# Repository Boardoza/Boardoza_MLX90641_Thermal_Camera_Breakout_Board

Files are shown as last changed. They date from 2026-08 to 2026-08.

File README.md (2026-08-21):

# Boardoza MLX90641 Thermal Camera Breakout Board

The **Boardoza MLX90641 Breakout Board** is a compact and high-performance thermal imaging solution built around the **Melexis MLX90641** far-infrared thermal sensor array. Featuring a **16x12 pixel thermal resolution**, the sensor delivers **192 independent temperature measurement points** for accurate non-contact thermal analysis and object detection applications.

Designed for compatibility with both **3.3V and 5V systems**, the board communicates over a high-speed **I<sup>2</sup>C interface** and supports configurable refresh rates up to **64Hz**. With a wide measurement range from **-40°C to +300°C** and a **55° X axis and 35° Y axis Field of View**, this breakout board is ideal for industrial monitoring, predictive maintenance, thermal mapping, robotics, occupancy sensing, smart appliances, and advanced embedded thermal imaging projects.

## [Click here to purchase!](https://www.ozdisan.com/ureticiler/boardoza)

|Front Side|Back Side|
|:---:|:---:|
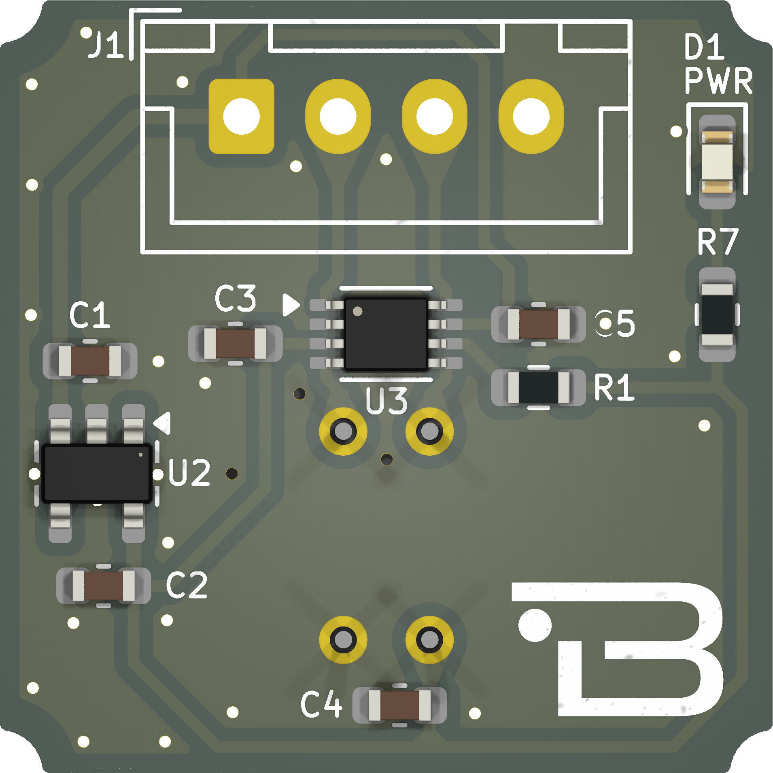
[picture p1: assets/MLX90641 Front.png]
MLX90641 Front
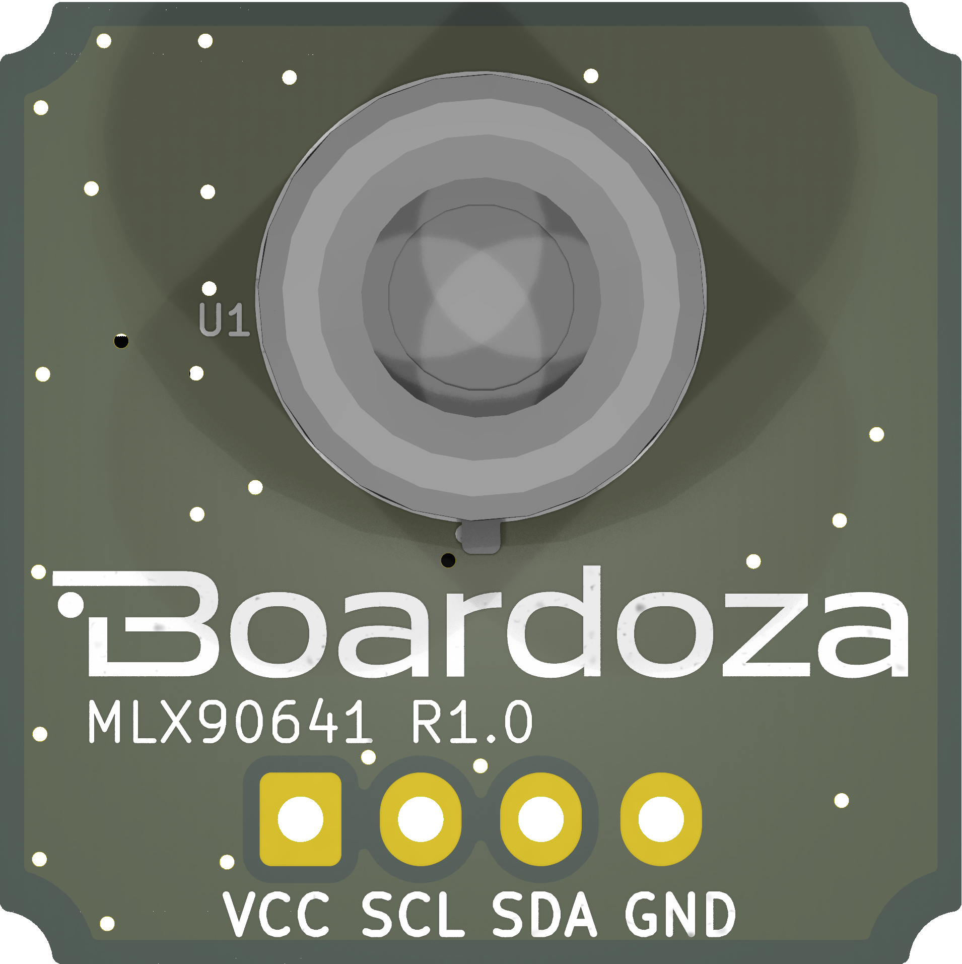
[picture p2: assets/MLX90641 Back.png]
MLX90641 Back
| | |

---

## Key Features

- **16x12 Thermal Imaging Array:** Captures 192 individual infrared temperature points for detailed thermal analysis.
- **Wide Temperature Measurement Range:** Measures object temperatures from **-40°C to +300°C** without physical contact.
- **Integrated Thermal Camera Functionality:** Enables compact thermal vision applications without requiring external optics.
- **Fast Refresh Rates:** Adjustable frame rates from **0.5Hz to 64Hz** for dynamic thermal monitoring.
- **Wide Compatibility:** Supports both **3.3V and 5V logic systems** for easy integration with popular development boards.
- **I<sup>2</sup>C Communication:** Supports I<sup>2</sup>C speeds up to **1MHz** for responsive thermal data transfer.
- **Wide Field of View:** Provides a **55° horizontal (X-axis)** and **35° vertical (Y-axis)** viewing angle for broader thermal coverage.  

---

## Technical Specifications

**Model:** MLX90641      
**Manufacturer:** Boardoza   
**Manufacturer IC:** Melexis   
**Functions:** Far-Infrared Thermal Imaging Sensor  
**Thermal Resolution:** 16 x 12 Pixels (192 Pixels)  
**Field of View (FoV):** 55° (X-axis) × 35° (Y-axis)  
**Measurement Range:** -40°C to +300°C  
**Supply Voltage (VCC):** 3.3V to 5.5V DC  
**Logic Voltage Level:** 3.3V / 5V Compatible  
**Communication Interface:** I<sup>2</sup>C  
**I<sup>2</sup>C Clock Frequency:** Up to 1 MHz  
**Sensor Refresh Rate:** 0.5Hz to 64Hz  
**Typical Current Consumption:** ~15mA  
**Operating Temperature:** -40°C to +85°C  
**Board Dimensions:** 20mm x 20mm  

---

## Board Pinout

### ( J1 ) I<sup>2</sup>C Connector

| Pin Number | Pin Name | Description |
|:---:|:---:|---|
| 1 | VCC | Voltage Supply Input |
| 2 | SCL | I<sup>2</sup>C Serial Clock |
| 3 | SDA | I<sup>2</sup>C Serial Data |
| 4 | GND | Ground |

---

## Board Dimensions

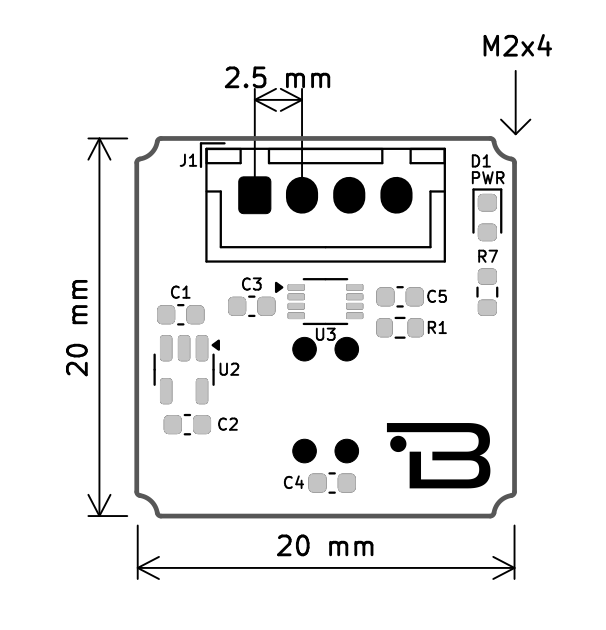
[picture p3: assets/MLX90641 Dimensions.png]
MLX90641 Board Dimensions


---

## Step Files

[Boardoza MLX90641.step](./assets/MLX90641%20Step.step)

---

## Datasheet

[MLX90641 Thermal Sensor Datasheet.pdf](./assets/MLX90641ESF-BCB-000-TU%20Datasheet.pdf)  
[TXS0102 Voltage Level Translator Datasheet.pdf](./assets/TXS0102DCU%20Datasheet.pdf)   
[TLV73333 3.3V LDO Regulator Datasheet.pdf](./assets/TLV73333PDBVR%20Datasheet.pdf)   

---

## Version History

- V1.0.0 - Initial Release

---

## Support

- If you have any questions or need support, please contact support@boardoza.com

---

## **License**

This repository contains both hardware and software components:

### **Hardware Design**

[][cc-by-sa]

All hardware design files are licensed under [Creative Commons Attribution-ShareAlike 4.0 International License][cc-by-sa].

[cc-by-sa]: http://creativecommons.org/licenses/by-sa/4.0/
[cc-by-sa-shield]: https://img.shields.io/badge/License-CC%20BY--SA%204.0-lightgrey.svg

### **Software/Firmware**

[][bsd]

All software and firmware are licensed under [BSD 3-Clause License][bsd].

[bsd]: https://opensource.org/licenses/BSD-3-Clause
[bsd-shield]: https://img.shields.io/badge/License-BSD%203--Clause-blue.svg

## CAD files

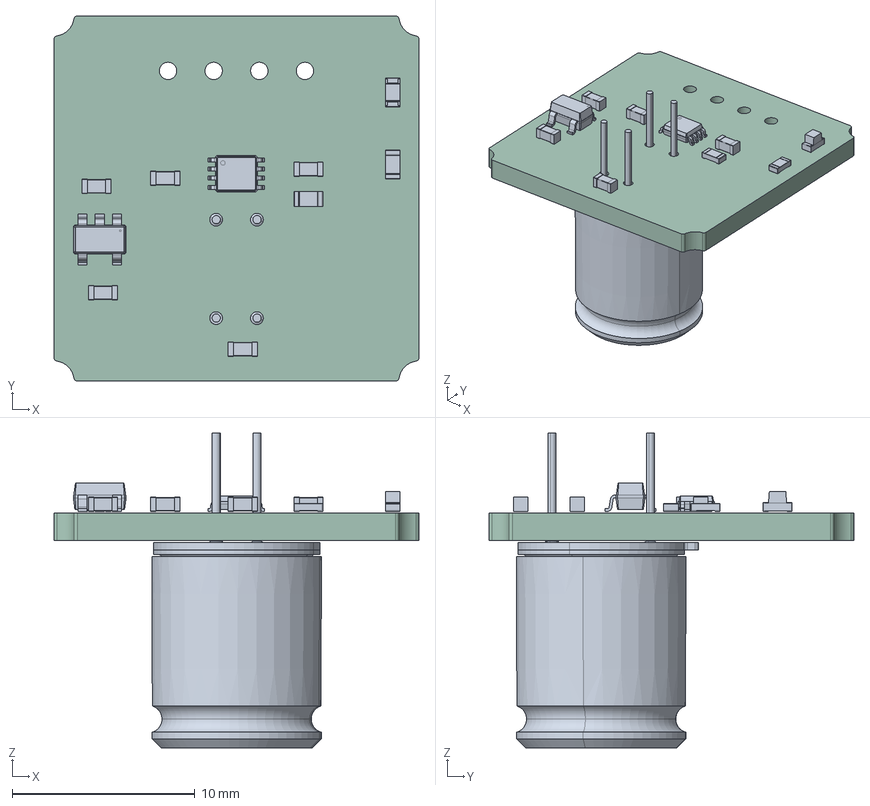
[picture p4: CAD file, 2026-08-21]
assets/MLX90641 Step.step
20.0 x 20.0 x 17.3 mm
R_0603_1608Metric x 2
VSSOP-8_2.3x2mm_P0.5mm
C_0603_1608Metric x 5
LED_0603_1608Metric
SOT-23-5
90640-GLASS_ANY x 3
90640PIN_ANY x 3
90640-BASE_ANY
90640-BRAZED-PIN_ANY
90640-60X15-APPERTURE_ANY
90640-LENSE_ANY
90640-CAP_ANY
_MLX90640-FOV60_BF1
kibot_3uhfzf03_PCB

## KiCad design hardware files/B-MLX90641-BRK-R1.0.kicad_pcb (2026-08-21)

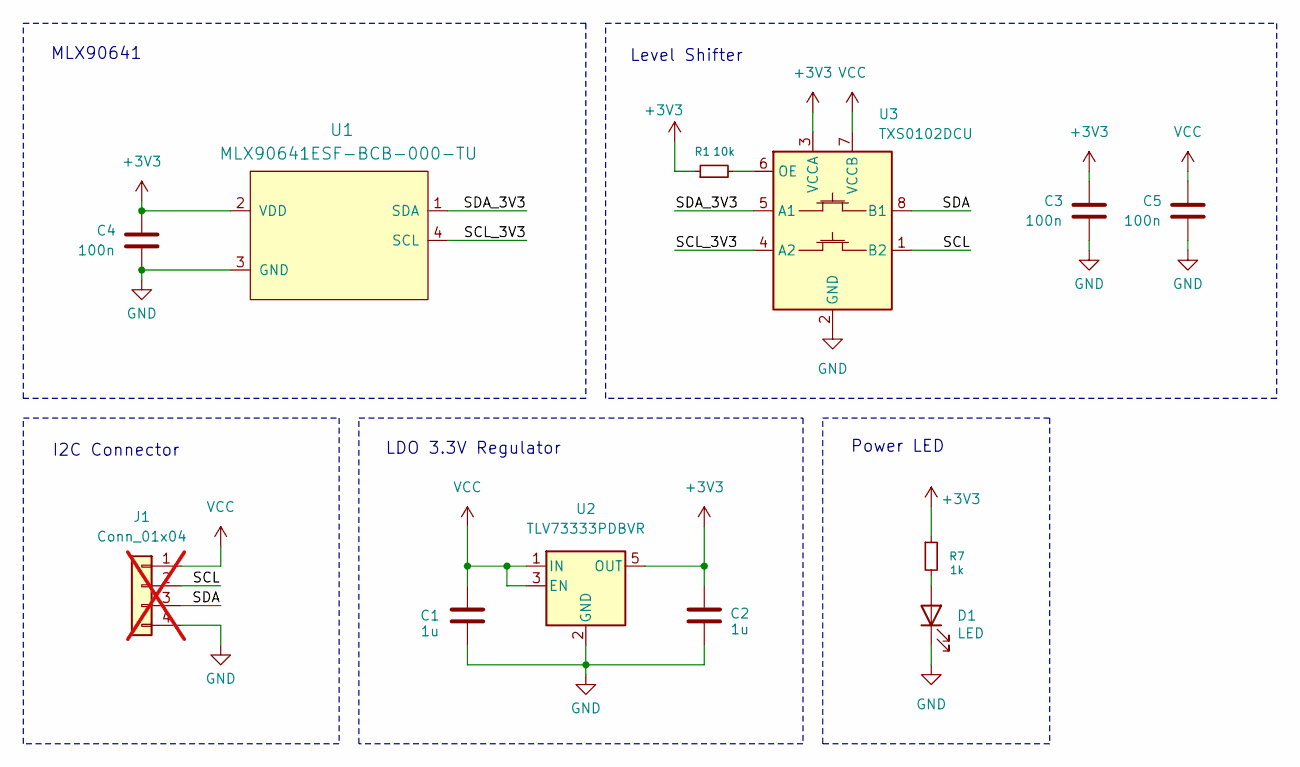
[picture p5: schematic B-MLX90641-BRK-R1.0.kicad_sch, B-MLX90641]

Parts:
C1, C2: 1u; C_0603_1608Metric; MANUFACTURER PART CL10A105KO8NNNC
C3, C4, C5: 100n; C_0603_1608Metric; MPN CL10B104KB8WPNC
D1: LED; LED_0603_1608Metric; MANUFACTURER PART LTST-C190KRKT
J1: Conn_01x04; JST_XH_B4B-XH-A_1x04_P2.50mm_Vertical; MPN L-KLS1-2.50-04-SB; not fitted
R1: 10k; R_0603_1608Metric; MANUFACTURER PART 0603SAJ0471T5E
R7: 1k; R_0603_1608Metric; MANUFACTURER PART 0603SAJ0471T5E
U1: MLX90641ESF-BCB-000-TU; MLX90641ESFBCB000TU; MPN MLX90641ESF-BCB-000-TU
U2: TLV73333PDBVR; SOT-23-5; MANUFACTURER PART TLV73333PDBVR
U3: TXS0102DCU; VSSOP-8_2.3x2mm_P0.5mm; MPN TXS0102DCUR

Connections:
+3V3: C2.1, C3.2, C4.2, R1.1, R7.1, U1.2 (VDD), U2.5 (OUT), U3.3 (VCCA)
/SCL: J1.2, U3.1 (B2)
/SCL_3V3: U1.4 (SCL), U3.4 (A2)
/SDA: J1.3, U3.8 (B1)
/SDA_3V3: U1.1 (SDA), U3.5 (A1)
GND: C1.1, C2.2, C3.1, C4.1, C5.1, D1.1 (K), J1.4, U1.3 (GND), U2.2 (GND), U3.2 (GND)
unnamed: D1.2 (A), R7.2
unnamed: R1.2, U3.6 (OE)
VCC: C1.2, C5.2, J1.1, U2.1 (IN), U2.3 (EN), U3.7 (VCCB)

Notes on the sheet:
LDO 3.3V Regulator
MLX90641
Power LED
Level Shifter
I2C Connector

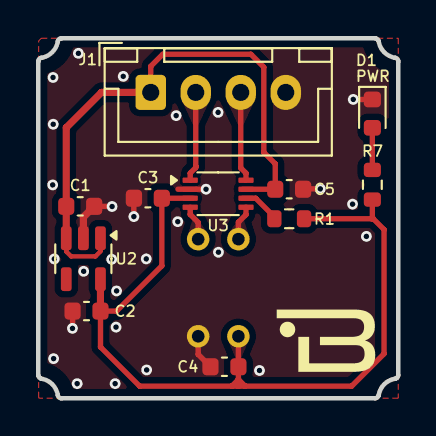
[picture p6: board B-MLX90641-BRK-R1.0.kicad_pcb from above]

Board: 2 copper layers, 20.0 x 20.0 mm, 12 parts (1 on the bottom side), 9 nets.

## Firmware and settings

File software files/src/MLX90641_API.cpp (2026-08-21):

/**
 * @copyright (C) 2017 Melexis N.V.
 *
 * Licensed under the Apache License, Version 2.0 (the "License");
 * you may not use this file except in compliance with the License.
 * You may obtain a copy of the License at
 *
 *     http://www.apache.org/licenses/LICENSE-2.0
 *
 * Unless required by applicable law or agreed to in writing, software
 * distributed under the License is distributed on an "AS IS" BASIS,
 * WITHOUT WARRANTIES OR CONDITIONS OF ANY KIND, either express or implied.
 * See the License for the specific language governing permissions and
 * limitations under the License.
 *
 */
#include <MLX9064X_I2C_Driver.h>
#include <MLX90641_API.h>
#include <math.h>
#include <Arduino.h>

void MLX90641_ExtractVDDParameters(uint16_t *eeData, paramsMLX90641 *mlx90641);
void MLX90641_ExtractPTATParameters(uint16_t *eeData, paramsMLX90641 *mlx90641);
void MLX90641_ExtractGainParameters(uint16_t *eeData, paramsMLX90641 *mlx90641);
void MLX90641_ExtractTgcParameters(uint16_t *eeData, paramsMLX90641 *mlx90641);
void MLX90641_ExtractEmissivityParameters(uint16_t *eeData, paramsMLX90641 *mlx90641);
void MLX90641_ExtractResolutionParameters(uint16_t *eeData, paramsMLX90641 *mlx90641);
void MLX90641_ExtractKsTaParameters(uint16_t *eeData, paramsMLX90641 *mlx90641);
void MLX90641_ExtractKsToParameters(uint16_t *eeData, paramsMLX90641 *mlx90641);
void MLX90641_ExtractAlphaParameters(uint16_t *eeData, paramsMLX90641 *mlx90641);
void MLX90641_ExtractOffsetParameters(uint16_t *eeData, paramsMLX90641 *mlx90641);
void MLX90641_ExtractKtaPixelParameters(uint16_t *eeData, paramsMLX90641 *mlx90641);
void MLX90641_ExtractKvPixelParameters(uint16_t *eeData, paramsMLX90641 *mlx90641);
void MLX90641_ExtractCPParameters(uint16_t *eeData, paramsMLX90641 *mlx90641);
int MLX90641_ExtractDeviatingPixels(uint16_t *eeData, paramsMLX90641 *mlx90641);
int MLX90641_HammingDecode(uint16_t *eeData);  
 

//------------------------------------------------------------------------------
  
int MLX90641_DumpEE(uint8_t slaveAddr, uint16_t *eeData)
{
     int error = 1;
     error = MLX9064x_I2CRead(slaveAddr, 0x2400, 832, eeData);
     if (error == 0)
     {
        error = MLX90641_HammingDecode(eeData);  
        Serial.println(error);
     }
         
     return error;
}

//------------------------------------------------------------------------------

int MLX90641_HammingDecode(uint16_t *eeData)
{
    int error = 0;
    int16_t parity[5];
    int8_t D[16];
    int16_t check;
    uint16_t data;
    uint16_t mask;
    
    for (int addr=16; addr<832; addr++)
    {
        parity[0] = -1;
        parity[1] = -1;
        parity[2] = -1;
        parity[3] = -1;
        parity[4] = -1;
        
        data = eeData[addr];
        mask = 1;
        for( int i = 0; i < 16; i++)
        {          
          D[i] = (data & mask) >> i;
          mask = mask << 1;
        }
        
        parity[0] = D[0]^D[1]^D[3]^D[4]^D[6]^D[8]^D[10]^D[11];
        parity[1] = D[0]^D[2]^D[3]^D[5]^D[6]^D[9]^D[10]^D[12];
        parity[2] = D[1]^D[2]^D[3]^D[7]^D[8]^D[9]^D[10]^D[13];
        parity[3] = D[4]^D[5]^D[6]^D[7]^D[8]^D[9]^D[10]^D[14];
        parity[4] = D[0]^D[1]^D[2]^D[3]^D[4]^D[5]^D[6]^D[7]^D[8]^D[9]^D[10]^D[11]^D[12]^D[13]^D[14]^D[15];
       
        if ((parity[0]!=0) || (parity[1]!=0) || (parity[2]!=0) || (parity[3]!=0) || (parity[4]!=0))
        {        
            check = (parity[0]<<0) + (parity[1]<<1) + (parity[2]<<2) + (parity[3]<<3) + (parity[4]<<4);
    
            if ((check > 15)&&(check < 32))
            {
                switch (check)
                {    
                    case 16:
                        D[15] = 1 - D[15];
                        break;
                    
                    case 24:
                        D[14] = 1 - D[14];
                        break;
                        
                    case 20:
                        D[13] = 1 - D[13];
                        break;
                        
                    case 18:
                        D[12] = 1 - D[12];
                        break;                                
                        
                    case 17:
                        D[11] = 1 - D[11];
                        break;
                        
                    case 31:
                        D[10] = 1 - D[10];
                        break;
                        
                    case 30:
                        D[9] = 1 - D[9];
                        break;
                    
                    case 29:
                        D[8] = 1 - D[8];
                        break;                
                    
                    case 28:
                        D[7] = 1 - D[7];
                        break;
                        
                    case 27:
                        D[6] = 1 - D[6];
                        break;
                            
                    case 26:
                        D[5] = 1 - D[5];
                        break;    
                        
                    case 25:
                        D[4] = 1 - D[4];
                        break;     
                        
                    case 23:
                        D[3] = 1 - D[3];
                        break; 
                        
                    case 22:
                        D[2] = 1 - D[2];
                        break; 
                            
                    case 21:
                        D[1] = 1 - D[1];
                        break; 
                        
                    case 19:
                        D[0] = 1 - D[0];
                        break;     
                                     
                }
               
                if(error == 0)
                {
                    error = -9;
                   
                }
                
                data = 0;
                mask = 1;
                for( int i = 0; i < 16; i++)
                {                    
                    data = data + D[i]*mask;
                    mask = mask << 1;
                }
       
            }
            else
            {
                error = -10;                
            }   
         }
        
        eeData[addr] = data & 0x07FF;
    }
    
    return error;
}

//------------------------------------------------------------------------------
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

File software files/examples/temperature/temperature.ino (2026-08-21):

#include <Arduino.h>


#define I2C_SDA 21   // Suitable SDA pin on NodeMCU S2
#define I2C_SCL 22   // Suitable SCL pin on NodeMCU S2
    
#include <Wire.h>

#include "MLX90641_API.h"
#include "MLX9064X_I2C_Driver.h"
#include "MLX90641_API.cpp"
#include "MLX9064X_I2C_Driver.cpp"

#define debug  Serial





const byte MLX90641_address = 0x33; //Default 7-bit unshifted address of the MLX90641

#define TA_SHIFT 8 //Default shift for MLX90641 in open air

static float mlx90641To[768];
paramsMLX90641 mlx90641;

//Returns true if the MLX90641 is detected on the I2C bus
boolean isConnected() {
    Wire.beginTransmission((uint8_t)MLX90641_address);
    if (Wire.endTransmission() != 0) {
        return (false);    //Sensor did not ACK
    }
    return (true);
}

void setup() {
    Wire.begin(1,2);
    Wire.setClock(400000); //Increase I2C clock speed to 400kHz

    debug.begin(115200);
    while (!debug); //Wait for user to open terminal
    debug.println("MLX90641 IR Array Example");
    if (isConnected() == false) {
        debug.println("MLX90640 not detected at default I2C address. Please check wiring. Freezing.");
        while (1);
    }
    debug.println("MLX90640 online!");
    debug.println("MLX90641 online!");

    //Get device parameters - We only have to do this once
    int status;
    uint16_t eeMLX90641[832];
    status = MLX90641_DumpEE(MLX90641_address, eeMLX90641);
    if (status != 0) {
        debug.println("Failed to load system parameters");
    }

    status = MLX90641_ExtractParameters(eeMLX90641, &mlx90641);
    if (status != 0) {
        debug.println("Parameter extraction failed");
    }
    MLX90641_SetRefreshRate(MLX90641_address, 0x07); //Set rate to 64H
    //Once params are extracted, we can release eeMLX90641 array
}

void loop() {
    for (byte x = 0 ; x < 2 ; x++) { //Read both subpages
        uint16_t mlx90641Frame[834];
        int status = MLX90641_GetFrameData(MLX90641_address, mlx90641Frame);
        if (status < 0) {
            debug.print("GetFrame Error: ");
            debug.println(status);
        }

        float vdd = MLX90641_GetVdd(mlx90641Frame, &mlx90641);
        float Ta = MLX90641_GetTa(mlx90641Frame, &mlx90641);

        float tr = Ta - TA_SHIFT; //Reflected temperature based on the sensor ambient temperature
        float emissivity = 0.95;

        MLX90641_CalculateTo(mlx90641Frame, &mlx90641, emissivity, tr, mlx90641To);
    }
  
    for (int x = 0 ; x < 192 ; x++) {
        debug.print(mlx90641To[x], 2);
        debug.print(",");
    }
    debug.println(""); 
}

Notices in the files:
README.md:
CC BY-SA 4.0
